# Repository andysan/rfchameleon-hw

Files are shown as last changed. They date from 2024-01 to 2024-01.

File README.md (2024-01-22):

<!--
SPDX-FileCopyrightText: Copyright 2023 Andreas Sandberg <andreas@sandberg.uk>

SPDX-License-Identifier: Apache-2.0
-->

# What is RF Chameleon

RF Chameleon is a set of tools to interface with ISM-band radios. It's
inspired by [RFQuack](https://rfquack.org/) but provides a more
abstract interface to the radio which implies that it needs to make
more assumptions about the underlying protocol. Unlike RFQuack, RF
Chameleon is not intended as an RF exploration tool. RF Chameleon is
intended to be used in the phase after basic exploration when the
underlying radio parameters are known.

This repository contains custom boards that have been designed
specifically for RF Chameleon.

# Firmware

See the
[rfchameleon-fw](https://github.com/rfchameleon/rfchameleon-fw)
project for more details.

# Boards

## RF Chameleon CC1101

This board is based on an STM32F401 and a [eByte
E07](https://www.cdebyte.com/products/E07-900MM10S) module containing
a [Texas Instruments CC1101](https://www.ti.com/product/CC1101) radio.

Early revisions of this board was known as the *RF McQuack CC1101*.

**Warning:** Revision 1 of this board has several known hardware
   defects that require patching before the board can be used.

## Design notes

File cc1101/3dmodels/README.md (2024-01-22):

# 3D models

Some 3D models are missing from KiCad need to be downloaded from
SnapEDA. They are not included in this repository as redistribution in
library form has somewhat unclear licensing terms.

* [LED_LiteOn_LTST-C19HE1WT.stp](https://www.snapeda.com/parts/LTST-C19HE1WT/Lite-On+Inc./view-part/)
* [Lightpipe_Dialight_515-1064F.stp](https://www.snapeda.com/parts/515-1064F/Dialight/view-part/)
* [SMA_Molex_73251-2120_EdgeMount_Horizontal.stp](https://www.snapeda.com/parts/73251-2123/Molex/view-part/)
* [SW_Push_1P1T-MP_NO_Horizontal_Alps_SKRTLAE010.stp](https://www.snapeda.com/parts/SKRTLAE010/ALPS/view-part/)
* [USB_C_Receptacle_HRO_TYPE-C-31-M-12.stp](https://www.snapeda.com/parts/TYPE-C-31-M-12/HRO+Electronics+Co.%252C+Ltd./view-part/)

Manufacturer alternatives:

* [SMA_Molex_73251-2120_EdgeMount_Horizontal.stp](https://www.molex.com/en-us/products/part-detail/732512120)
* [Lightpipe_Dialight_515-1064F.stp](https://www.dialightsignalsandcomponents.com/515-optopipe-light-pipe-trilevel-2-5mm-rnd-flat-diff-lens-press-fit/)

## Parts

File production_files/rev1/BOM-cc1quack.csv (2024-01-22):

Comment | Designator | Footprint | LCSC
120R/0.5A | FB201,FB202,FB203 | L_0805_2012Metric | C1015
Alps SKRTLAE010 | SW401 | SW_Push_1P1T-MP_NO_Horizontal_Alps_SKRTLAE010 | C110293
8MHz 20pF | Y401 | Crystal_SMD_HC49-SD | C12674
100nF | C203,C204,C401,C405,C407,C409,C410,C411,C412,C501 | C_0603_1608Metric | C14663
1uF | C302,C303,C404,C502 | C_0603_1608Metric | C15849
20pF C0G | C402,C403 | C_0603_1608Metric | C1648
USB_C_Receptacle | J201 | USB_C_Receptacle_HRO_TYPE-C-31-M-12 | C165948
1N5819WS | D301,D302 | D_SOD-323 | C191023
4.7uF | C301,C408 | C_0603_1608Metric | C19666
150R | R114,R117,R120 | R_0603_1608Metric | C22808
47R | R115,R116,R118,R119,R121,R122 | R_0603_1608Metric | C23182
5k1, 20% | R201,R202 | R_0603_1608Metric | C23186
82k | R403 | R_0603_1608Metric | C23254
2.2uF X5R | C406 | C_0603_1608Metric | C23630
10k | R401,R402,R405 | R_0603_1608Metric | C25804
33k | R404 | R_0603_1608Metric | C4216
LED | D103,D104,D105 | LED_LiteOn_LTST-C19HE1WT | C458749
XC6206P332MR | U301 | SOT-23 | C5446
10nF | C202 | C_0603_1608Metric | C57112
SRV05-4 | D201 | SOT-23-6 | C7420376
STM32F401RCT6 | U401 | LQFP-64_10x10mm_P0.5mm | C74524

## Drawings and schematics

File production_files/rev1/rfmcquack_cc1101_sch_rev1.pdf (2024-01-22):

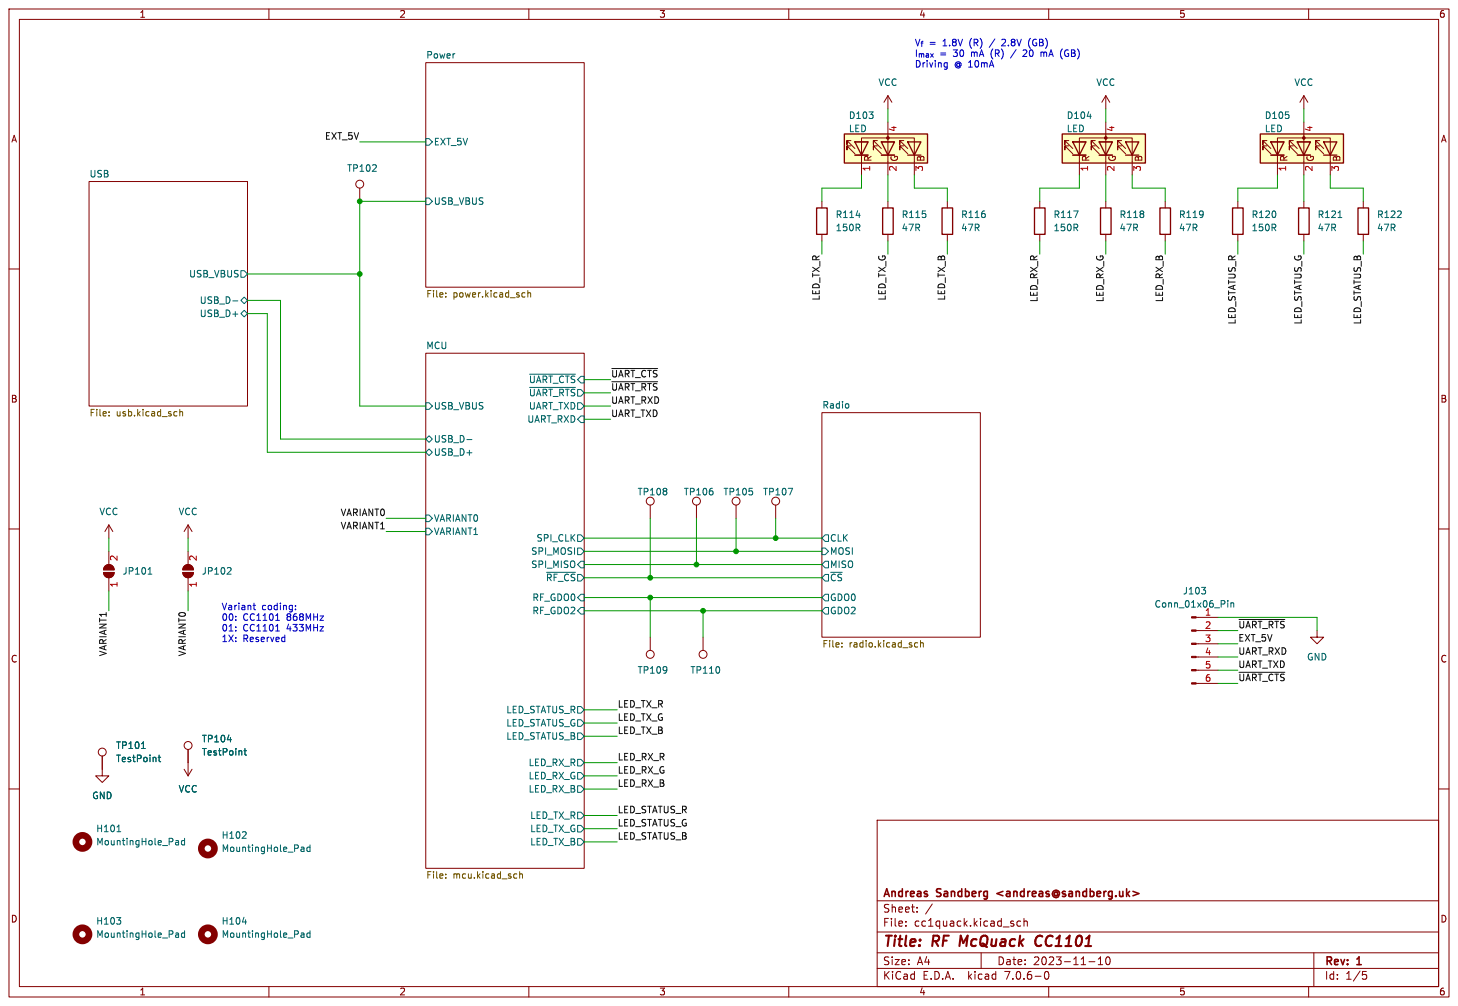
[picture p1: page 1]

I_{max}= 30 mA (R) / 20 mA (GB)
Driving @ 10mA

Radio File: radio.kicad_sch USB_D- USB_D+ USB_VBUS USB

File: cc1quack.kicad_sch Sheet: / Andreas Sandberg <andreas@sandberg.uk> GDO2 GDO0 ~{CS} MOSI CLK MISO

Id: 1/5 Title: RF McQuack CC1101

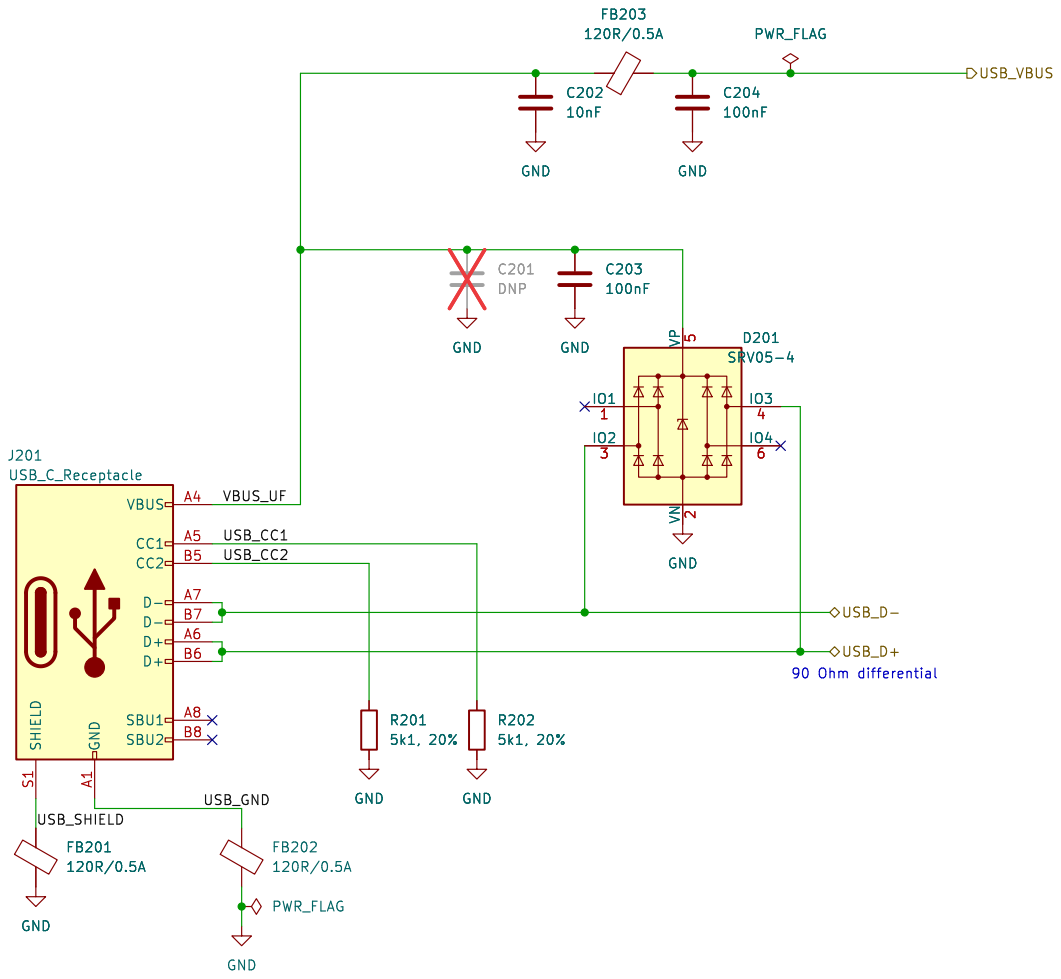
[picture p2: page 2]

File: usb.kicad_sch Sheet: /USB/ Andreas Sandberg <andreas@sandberg.uk>

Id: 2/5 Title: RF McQuack CC1101

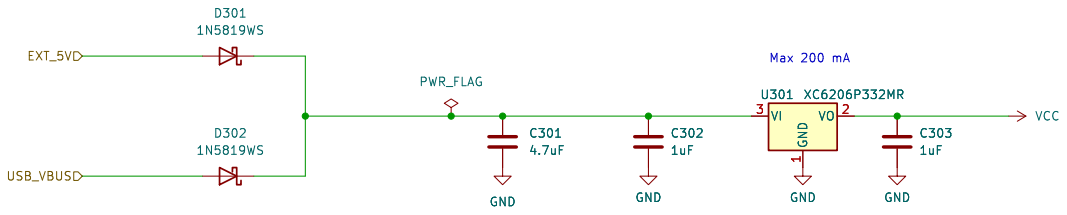
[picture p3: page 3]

File: power.kicad_sch Sheet: /Power/ Andreas Sandberg <andreas@sandberg.uk>

Id: 3/5 Title: RF McQuack CC1101

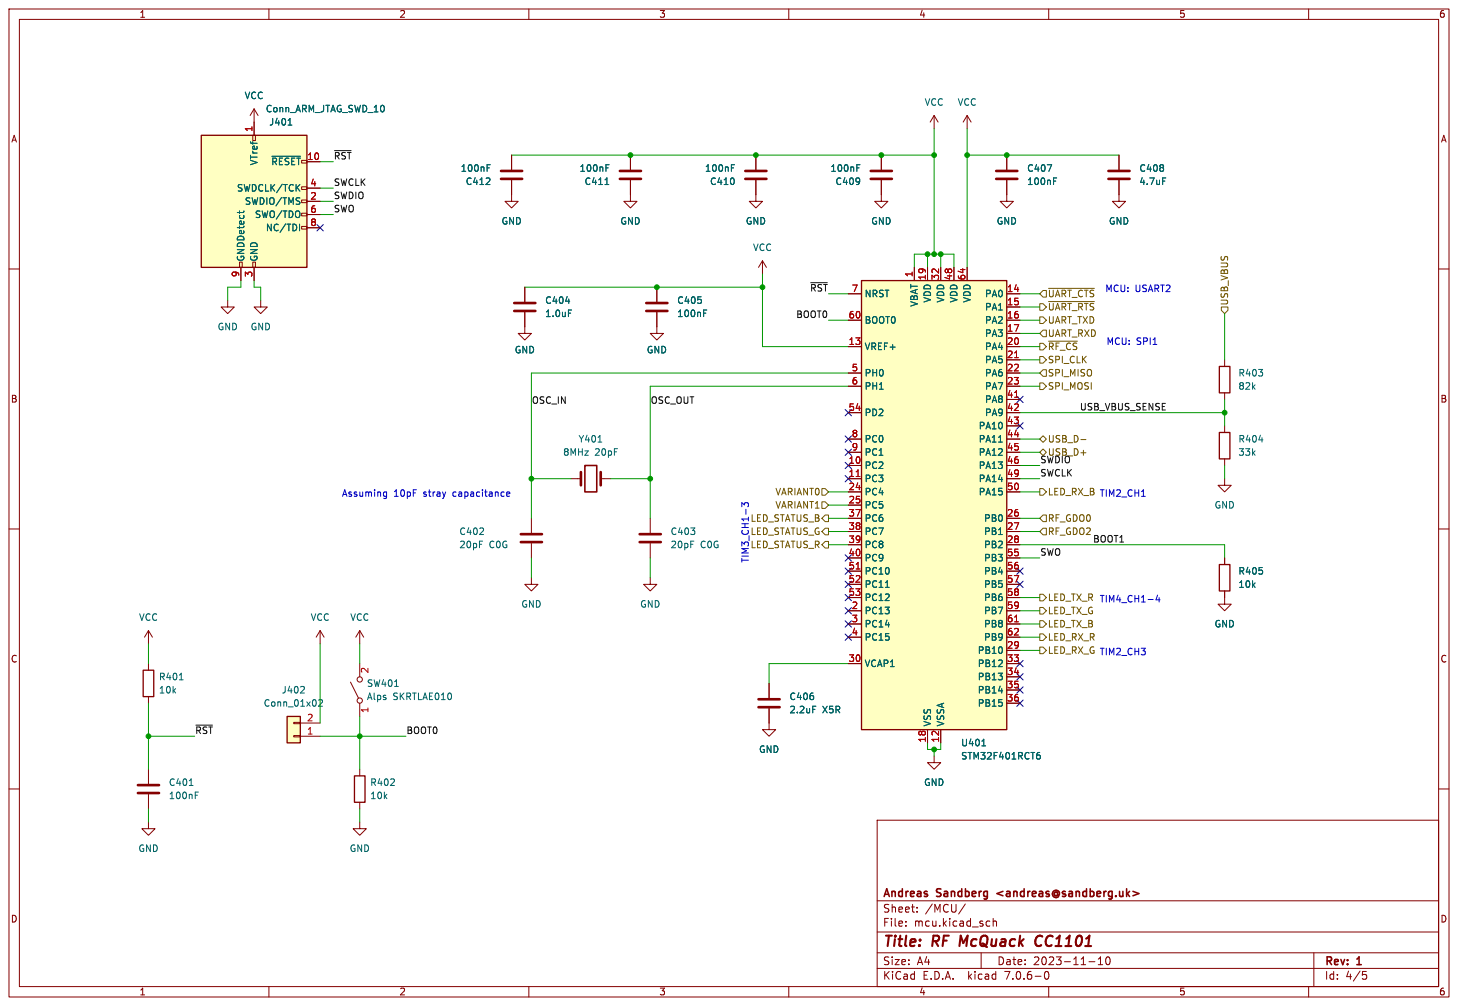
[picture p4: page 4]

3 SWDCLK/TCK 4 SWO/TDO 6 NC/TDI 8 GNDDetect 9 VCC

3 SWDCLK/TCK 4 SWO/TDO 6 NC/TDI 8 GNDDetect 9

1 PC2 10 PC3 11 VSSA 12 VREF+ 13 PA0 14 PA1 15 PA2 16 PA3 17 VSS 18 VDD 19 PC13 2 PA4 20 PA5 21 PA6 22 PA7 23 PC4 24 PC5 25 PB0 26 PB1 27 PB2 28 PB10 29 PC14 3 VCAP1 30 VDD 32 PB12 33 PB13 34 PB14 35 PB15 36 PC6 37 PC7 38 PC8 39 PC15 4 PC9 40 PA8 41 PA9 42 PA10 43 PA11 44 PA12 45 PA13 46 VDD 48 PA14 49 PH0 5 PA15 50 PC10 51 PC11 52 PC12 53 PD2 54 PB3 55 PB4 56 PB5 57 PB6 58 PB7 59 PH1 6 BOOT0 60 PB8 61 PB9 62 VDD 64 NRST 7 PC0 8 PC1 9 C404
~{RST} OSC_IN

1 PC2 10 PC3 11 VSSA 12 VREF+ 13 PA0 14 PA1 15 PA2 16 PA3 17 VSS 18 VDD 19 PC13 2 PA4 20 PA5 21 PA6 22 PA7 23 PC4 24 PC5 25 PB0 26 PB1 27 PB2 28 PB10 29 PC14 3 VCAP1 30 VDD 32 PB12 33 PB13 34 PB14 35 PB15 36 PC6 37 PC7 38 PC8 39 PC15 4 PC9 40 PA8 41 PA9 42 PA10 43 PA11 44 PA12 45 PA13 46 VDD 48 PA14 49 PH0 5 PA15 50 PC10 51 PC11 52 PC12 53 PD2 54 PB3 55 PB4 56 PB5 57 PB6 58 PB7 59 PH1 6 BOOT0 60 PB8 61 PB9 62 VDD 64 NRST 7 PC0 8 PC1 9 U401 STM32F401RCT6 GND

File: mcu.kicad_sch Sheet: /MCU/ Andreas Sandberg <andreas@sandberg.uk>

Id: 4/5 Title: RF McQuack CC1101

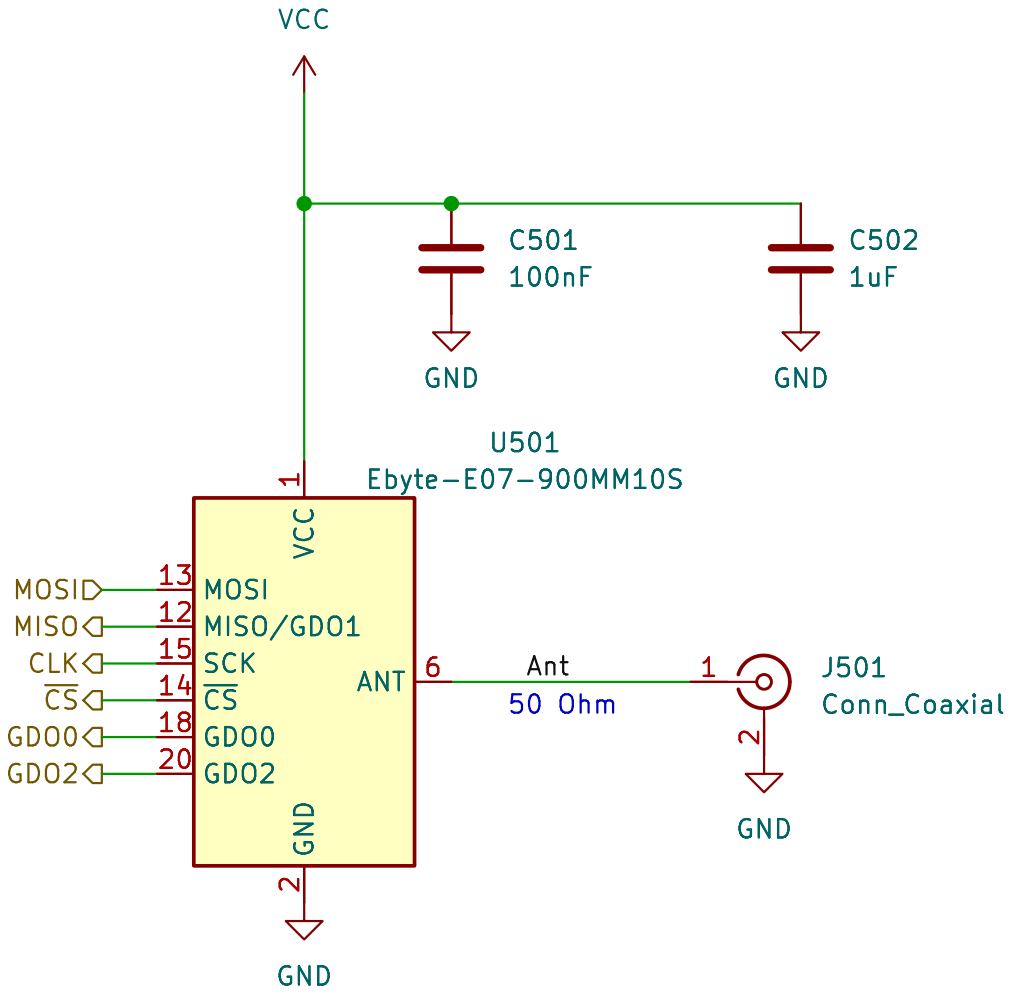
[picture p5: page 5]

1 MISO/GDO1 12 MOSI 13 ~{CS} 14 SCK 15 GDO0 18 GND

J501 Conn_Coaxial GND MOSI CLK MISO

File: radio.kicad_sch Sheet: /Radio/ Andreas Sandberg <andreas@sandberg.uk>

Id: 5/5 Title: RF McQuack CC1101

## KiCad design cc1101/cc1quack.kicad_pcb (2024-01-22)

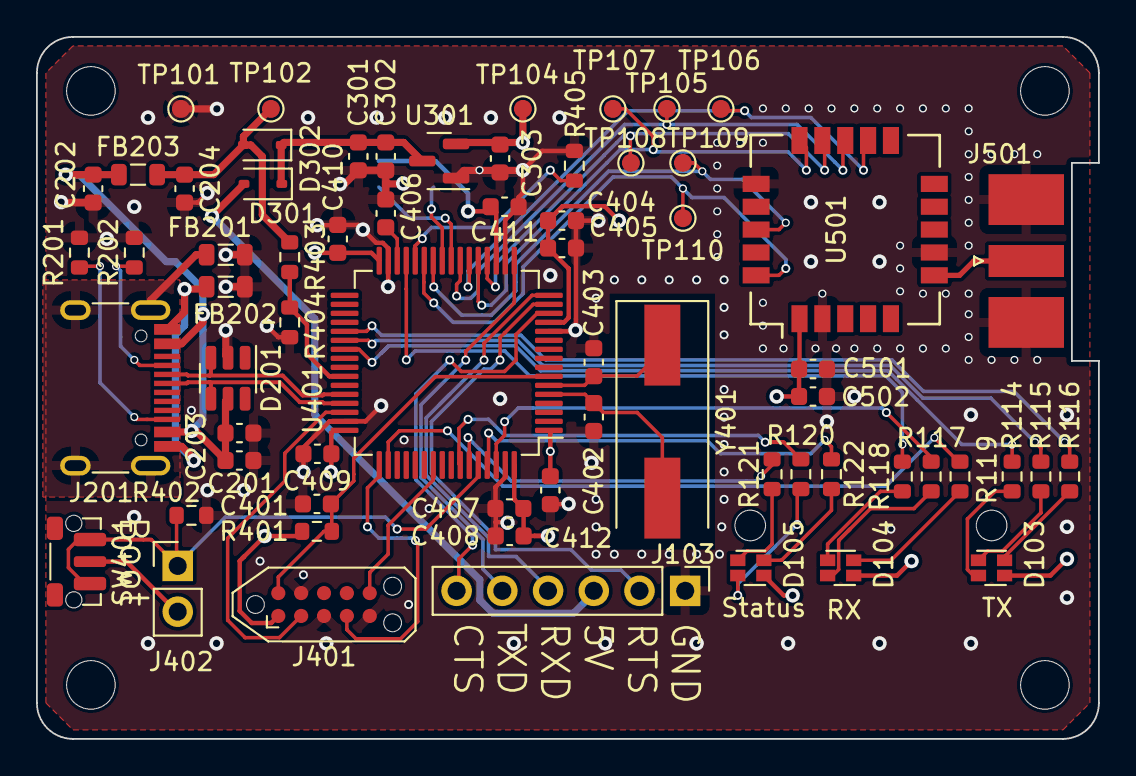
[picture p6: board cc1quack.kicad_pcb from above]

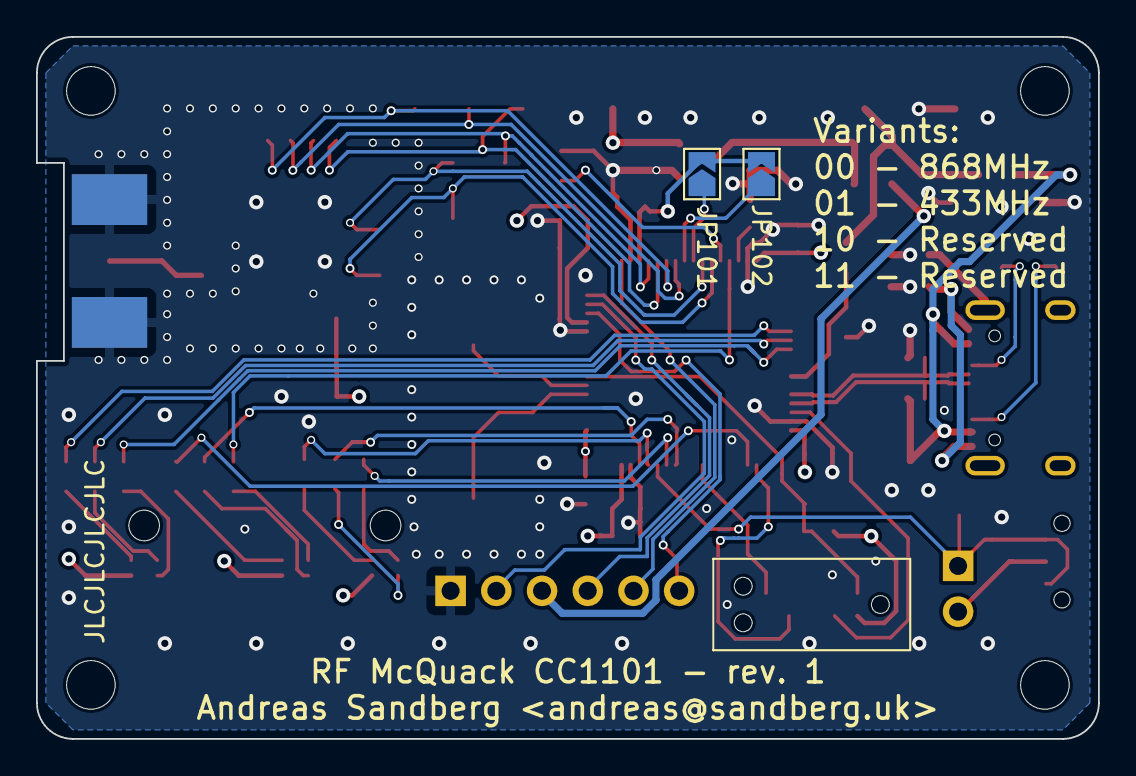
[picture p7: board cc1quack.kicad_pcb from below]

Board: 4 copper layers, 59.0 x 39.0 mm, 71 parts (2 on the bottom side), 53 nets.

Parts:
C201: DNP; C_0603_1608Metric
C202: 10nF; C_0603_1608Metric
C203, C204, C401, C405, C407, C409, C410, C411, C412, C501: 100nF; C_0603_1608Metric
C301, C408: 4.7uF; C_0603_1608Metric
C302, C303, C502: 1uF; C_0603_1608Metric
C402, C403: 20pF C0G; C_0603_1608Metric
C404: 1.0uF; C_0603_1608Metric
C406: 2.2uF X5R; C_0603_1608Metric
D103, D104, D105: LED; LED_LiteOn_LTST-C19HE1WT
D201: SRV05-4; SOT-23-6
D301, D302: 1N5819WS; D_SOD-323
FB201, FB202, FB203: 120R/0.5A; L_0805_2012Metric
H101, H102, H103, H104: MountingHole_Pad; MountingHole_2.7mm_M2.5
J103: Conn_01x06_Pin; PinHeader_1x06_P2.54mm_Vertical
J201: USB_C_Receptacle; USB_C_Receptacle_HRO_TYPE-C-31-M-12
J401: Conn_ARM_JTAG_SWD_10; Tag-Connect_TC2050-IDC-NL_2x05_P1.27mm_Vertical_with_bottom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
J402: Conn_01x02; PinHeader_1x02_P2.54mm_Vertical
J501: Conn_Coaxial; SMA_Molex_73251-2120_EdgeMount_Horizontal
JP101, JP102: SolderJumper_2_Open; SolderJumper-2_P1.3mm_Open_TrianglePad1.0x1.5mm
R114, R117, R120: 150R; R_0603_1608Metric
R115, R116, R118, R119, R121, R122: 47R; R_0603_1608Metric
R201, R202: 5k1, 20%; R_0603_1608Metric
R401, R402, R405: 10k; R_0603_1608Metric
R403: 82k; R_0603_1608Metric
R404: 33k; R_0603_1608Metric
SW401: Alps SKRTLAE010; SW_Push_1P1T-MP_NO_Horizontal_Alps_SKRTLAE010
TP101, TP102, TP104, TP105, TP106, TP107, TP108, TP109, TP110: TestPoint; TestPoint_Pad_D1.0mm
U301: XC6206P332MR; SOT-23
U401: STM32F401RCT6; LQFP-64_10x10mm_P0.5mm
U501: Ebyte-E07-900MM10S; Ebyte E07-400MM10S
Y401: 8MHz 20pF; Crystal_SMD_HC49-SD

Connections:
/EXT_5V: D301.2 (A), J103.3
/LED_RX_B: R119.2, U401.50 (PA15)
/LED_RX_G: R118.2, U401.29 (PB10)
/LED_RX_R: R117.2, U401.62 (PB9)
/LED_STATUS_B: R122.2, U401.61 (PB8)
/LED_STATUS_G: R121.2, U401.59 (PB7)
/LED_STATUS_R: R120.2, U401.58 (PB6)
/LED_TX_B: R116.2, U401.37 (PC6)
/LED_TX_G: R115.2, U401.38 (PC7)
/LED_TX_R: R114.2, U401.39 (PC8)
/MCU/BOOT0: J402.1, R402.1, SW401.1 (A), U401.60 (BOOT0)
/MCU/BOOT1: R405.2, U401.28 (PB2)
/MCU/OSC_IN: C402.1, U401.5 (PH0), Y401.2
/MCU/OSC_OUT: C403.1, U401.6 (PH1), Y401.1
/MCU/RF_GDO0: TP109.1, U401.26 (PB0), U501.18 (GDO0)
/MCU/RF_GDO2: TP110.1, U401.27 (PB1), U501.20 (GDO2)
/MCU/SPI_CLK: TP107.1, U401.21 (PA5), U501.15 (SCK)
/MCU/SPI_MISO: TP106.1, U401.22 (PA6), U501.12 (MISO/GDO1)
/MCU/SPI_MOSI: TP105.1, U401.23 (PA7), U501.13 (MOSI)
/MCU/SWCLK: J401.4 (SWDCLK/TCK), U401.49 (PA14)
/MCU/SWDIO: J401.2 (SWDIO/TMS), U401.46 (PA13)
/MCU/SWO: J401.6 (SWO/TDO), U401.55 (PB3)
/MCU/USB_D+: D201.4 (IO3), J201.A6 (D+), J201.B6 (D+), U401.45 (PA12)
/MCU/USB_D-: D201.3 (IO2), J201.A7 (D-), J201.B7 (D-), U401.44 (PA11)
/MCU/USB_VBUS: C204.1, D302.2 (A), FB203.2, R403.1, TP102.1
/MCU/USB_VBUS_SENSE: R403.2, R404.1, U401.42 (PA9)
/MCU/~RF_CS: TP108.1, U401.20 (PA4), U501.14 (~CS)
/MCU/~RST: C401.2, J401.10 (~RESET), R401.2, U401.7 (NRST)
/Radio/Ant: J501.1 (In), U501.6 (ANT)
/UART_RXD: J103.4, U401.16 (PA2)
/UART_TXD: J103.5, U401.17 (PA3)
/USB/USB_CC1: J201.A5 (CC1), R202.1
/USB/USB_CC2: J201.B5 (CC2), R201.1
/USB/USB_GND: FB202.1, J201.A1 (GND), J201.A12 (GND), J201.B1 (GND), J201.B12 (GND)
/USB/USB_SHIELD: FB201.1, J201.S1 (SHIELD)
/USB/VBUS_UF: C201.1, C202.1, C203.1, D201.5 (VP), FB203.1, J201.A4 (VBUS), J201.A9 (VBUS), J201.B4 (VBUS), J201.B9 (VBUS)
/VARIANT0: JP102.1 (A), U401.24 (PC4)
/VARIANT1: JP101.1 (A), U401.25 (PC5)
/~UART_CTS: J103.6, U401.14 (PA0)
/~UART_RTS: J103.2, U401.15 (PA1)
GND: C201.2, C202.2, C203.2, C204.2, C301.2, C302.2, C303.2, C401.1, C402.2, C403.2, C404.1, C405.1, C406.1, C407.1, C408.1, C409.2, C410.2, C411.2, C412.2, C501.1, C502.2, D201.2 (VN), FB201.2, FB202.2, J103.1, J401.3 (GND), J401.5 (GND), J401.9 (GNDDetect), J501.2 (Ext), R201.2, R202.2, R402.2, R404.2, R405.1, TP101.1, U301.1 (GND), U401.12 (VSSA), U401.18 (VSS), U401.31 (VSS), U401.47 (VSS), U401.63 (VSS), U501.2 (GND), U501.7 (GND), U501.16 (GND)
unnamed: D103.3 (BK), R116.1
unnamed: D103.2 (GK), R115.1
unnamed: D103.1 (RK), R114.1
unnamed: D104.3 (BK), R119.1
unnamed: D104.2 (GK), R118.1
unnamed: D104.1 (RK), R117.1
unnamed: D105.3 (BK), R122.1
unnamed: D105.2 (GK), R121.1
unnamed: D105.1 (RK), R120.1
unnamed: C301.1, C302.1, D301.1 (K), D302.1 (K), U301.3 (VI)
unnamed: C406.2, U401.30 (VCAP1)
VCC: C303.1, C404.2, C405.2, C407.2, C408.2, C409.1, C410.1, C411.1, C412.1, C501.2, C502.1, D103.4 (A), D104.4 (A), D105.4 (A), J401.1 (VTref), J402.2, JP101.2 (B), JP102.2 (B), R401.1, SW401.2 (B), TP104.1, U301.2 (VO), U401.1 (VBAT), U401.13 (VREF+), U401.19 (VDD), U401.32 (VDD), U401.48 (VDD), U401.64 (VDD), U501.1 (VCC)

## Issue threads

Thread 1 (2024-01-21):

Update PCB design to reflect name change from RF McQuack CC1101 to RF Chameleon CC1101

andysan, 2024-01-21:
The working name of this project was originally RF McQuack which is still present in some of the design files. This needs to be updated to RF Chameleon.

- [ ] Rename PCB design files
- [ ] Update schematic metadata
- [ ] Update PCB metadata
- [ ] Update PCB silkscreen

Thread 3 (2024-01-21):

USB-C connector is wired incorrectly

andysan, 2024-01-21:
The D+/D- nets haven't been routed to B6/A7 on the USB-C connector. This prevents USB from functioning correctly.

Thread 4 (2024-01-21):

RX and TX swapped on UART

andysan, 2024-01-21:
RX and TX have been swapped on the FTDI UART header. It seems like this was incorrectly routed in the top-level schematic.

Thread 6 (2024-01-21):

Resistors in VBUS voltage divider have been swapped

andysan, 2024-01-21:
Resistors in VBUS voltage divider has been swapped. Pin is 5V tolerant, voltage must be kept below 4V in case to be within spec when MCU is off but VBUS is on.

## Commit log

2024-01-22 Add RF McQuack CC1101 rev 1 schematics and PCB
    [cc1quack.kicad_pcb, cc1quack.kicad_sch, mcu.kicad_sch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]
2024-01-22 cc1quack: Add specialized switch footprint
    Specialize the ALPS SKRTLAE010 to include project-specific 3D model
    paths.
    [cc1quack.kicad_pcb, mcu.kicad_sch]
2024-01-22 cc1quack: Include both WRL and STP model paths
    [cc1quack.kicad_pcb]
2024-01-22 cc1quack: Specialize LiteOn LTST C19HE1WT footprint
    Specialize LiteOn LTST C19HE1WT footprint to include 3D models.
    [cc1quack.kicad_pcb, cc1quack.kicad_sch]
2024-01-22 Add revision 1 production files
    Add production files used for revision one of the CC1101-based PCB.
    [BOM-cc1quack.csv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]
